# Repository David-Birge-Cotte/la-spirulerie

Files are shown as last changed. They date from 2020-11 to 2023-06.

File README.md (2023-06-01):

# la-spirulerie

www.la-spirulerie.com/

------------------------------------------------------------

/MK3_Firmware

Code source du logiciel officiel installé sur la carte Spirulerie. 
Projet Platform.IO écrit en C++ Arduino pour ESP32. 
Il faut installer l'image système pour le rendu correct des polices d'écriture sur l'interface.

/STL

Modèles 3D à imprimer du bioréacteur Spirulerie et du boitier de carte standalone.

/Guide Bioréacteur Spirulerie

Guide PDF rapide de la culture de spiruline et d'utilisation du bioréacteur Spirulerie.

/LibSpirulerie

Bibliothèque Arduino (PlatformIO) pour simplifier la programmation de la carte Spirulerie. Version 0.0.1 Work in progress

------------------------------------------------------------

/MK3_Firmware

Official firmware installed on La Spirulerie's motherboard.
Platform.IO project written in Arduino C++ for ESP32. 
You need to install file systme image to correctly render fonts.

/STL

3D printable files from La Spirulerie's Bioreactor and standalone board in the STL folder.

/Guide Bioréacteur Spirulerie

(FR) Quick guide about spirulina cultivation and the use of La Spirulerie's bioreactor.

/LibSpirulerie

Arduino (PlatformIO) library to make programming the board easier. Version 0.0.1 Work in progress

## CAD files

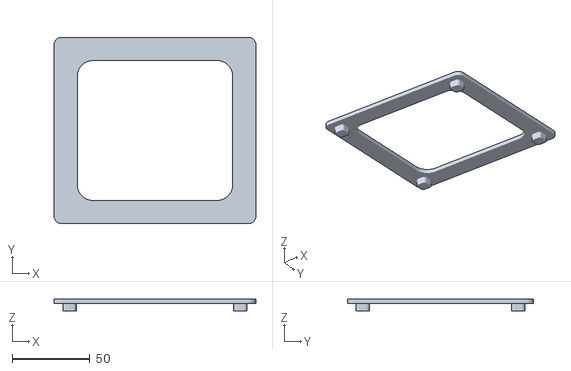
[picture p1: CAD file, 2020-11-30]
STL/boitier/Porte_Boitier.stl
130.0 x 120.0 x 8.00

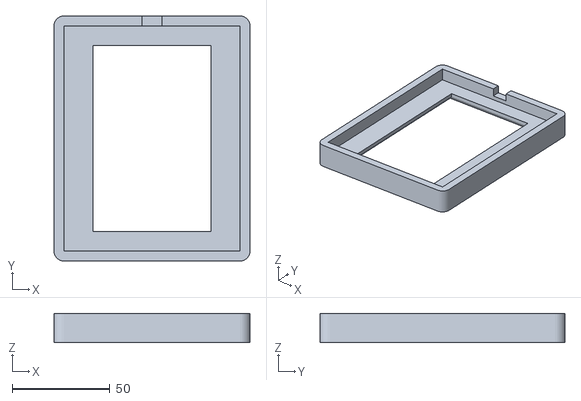
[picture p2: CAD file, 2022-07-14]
STL/chauffage/Protection_chauffage.stl
100.0 x 125.0 x 15.0

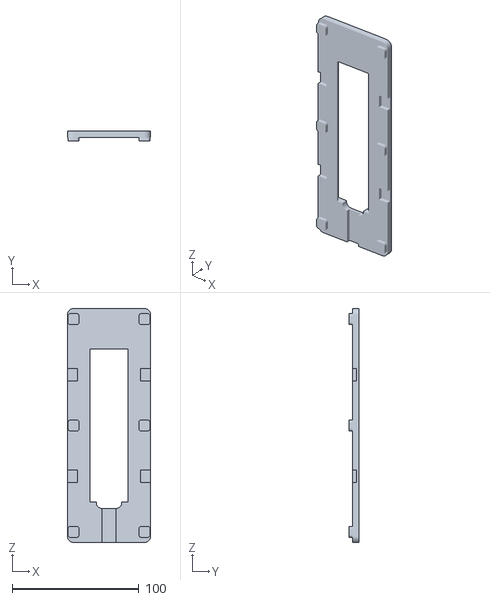
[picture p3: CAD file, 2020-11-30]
STL/couvercle/Côté/Couvercle_COB.stl
65.8 x 7.80 x 184.8

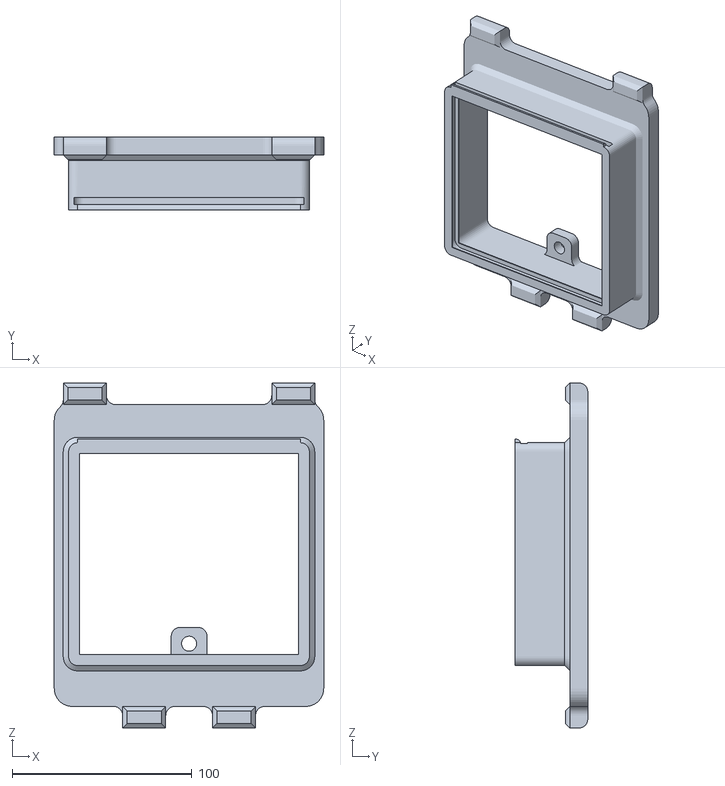
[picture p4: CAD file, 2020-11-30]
STL/couvercle/Recolte/Bac_récolte.stl
150.0 x 40.5 x 192.0

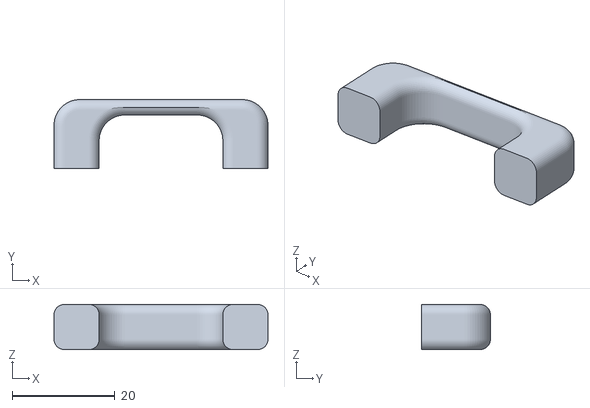
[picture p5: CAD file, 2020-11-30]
STL/interface/passe_cables.stl
41.7 x 13.4 x 8.80

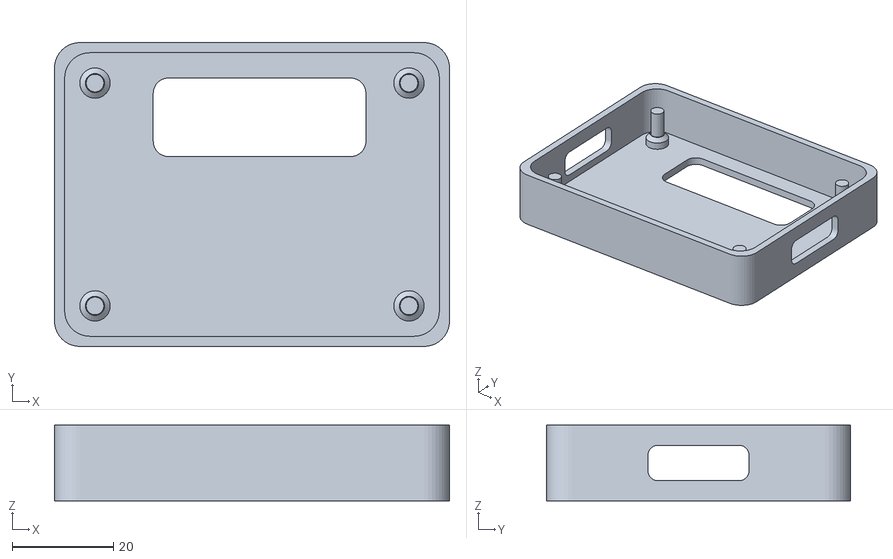
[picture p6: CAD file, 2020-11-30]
STL/interface/standalone/interface_bas_new.stl
78.0 x 60.0 x 15.0

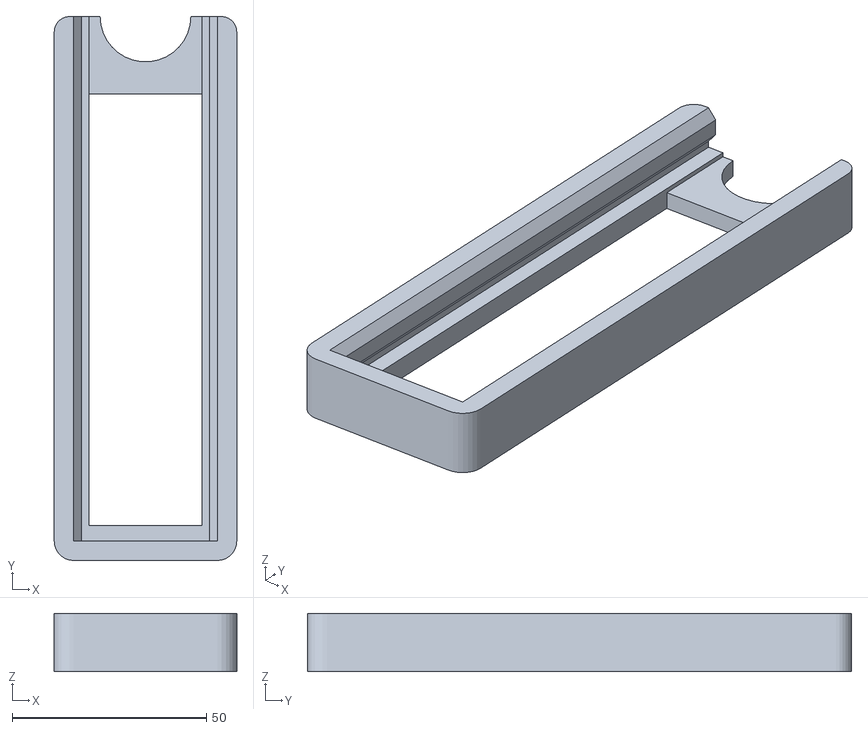
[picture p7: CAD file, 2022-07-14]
STL/porte_LED_collable_120_35.stl
47.0 x 140.0 x 15.0

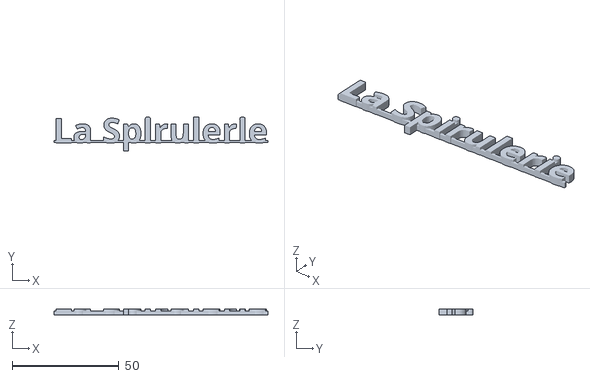
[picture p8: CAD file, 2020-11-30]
STL/white_glued_prints/Spirulerie_Text.stl
100.0 x 16.0 x 3.00

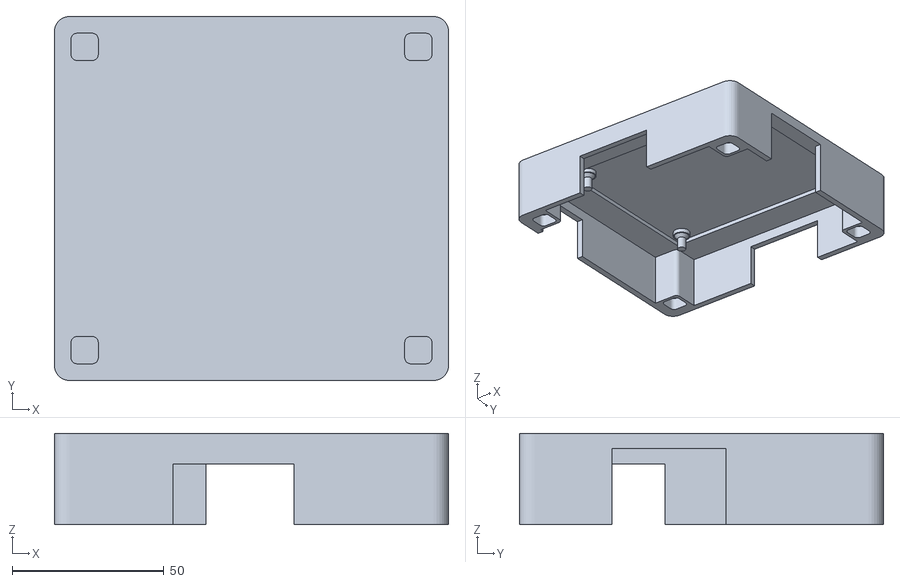
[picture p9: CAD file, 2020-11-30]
STL/boitier/Boitier_PCB.stl
130.0 x 120.0 x 30.0

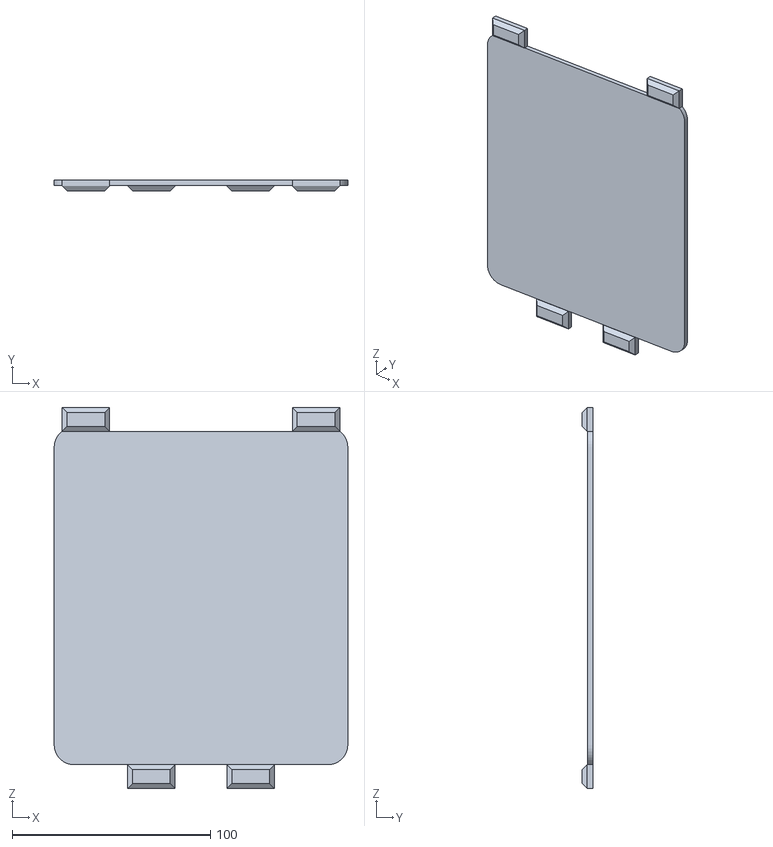
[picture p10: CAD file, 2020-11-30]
STL/couvercle/Centre/Couvercle_fermé _2mm.stl
148.0 x 5.50 x 192.0

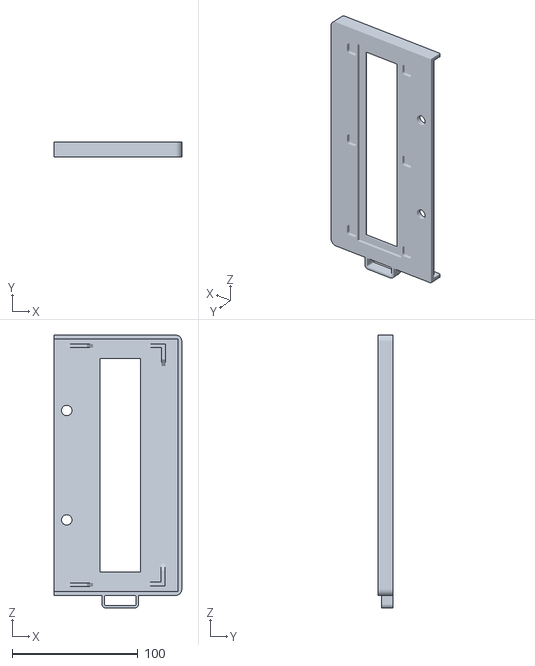
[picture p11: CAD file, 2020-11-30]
STL/couvercle/Côté/Couvercle_base.stl
101.5 x 12.0 x 217.0

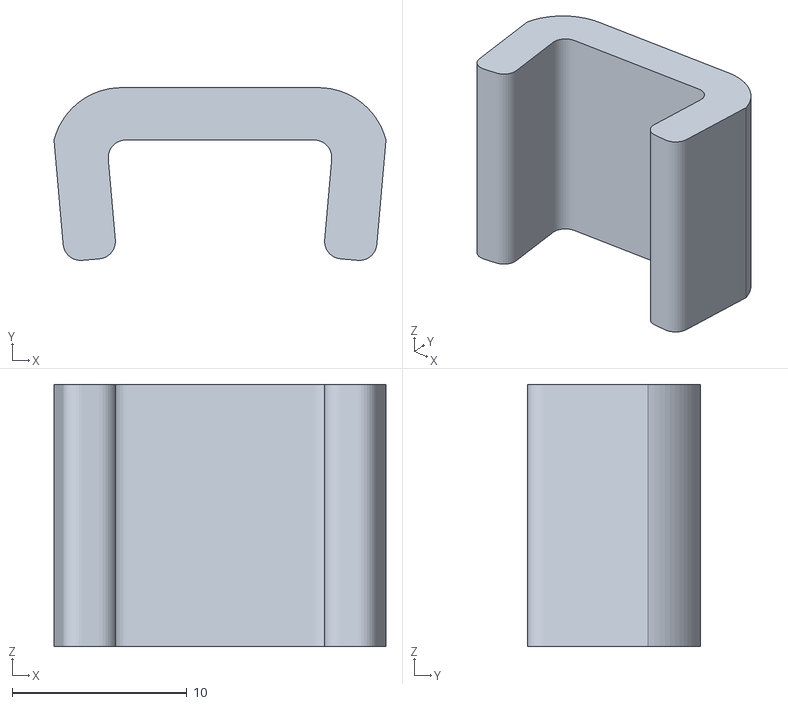
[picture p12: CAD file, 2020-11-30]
STL/couvercle/Recolte/Pince_filtre.stl
19.0 x 9.89 x 15.0

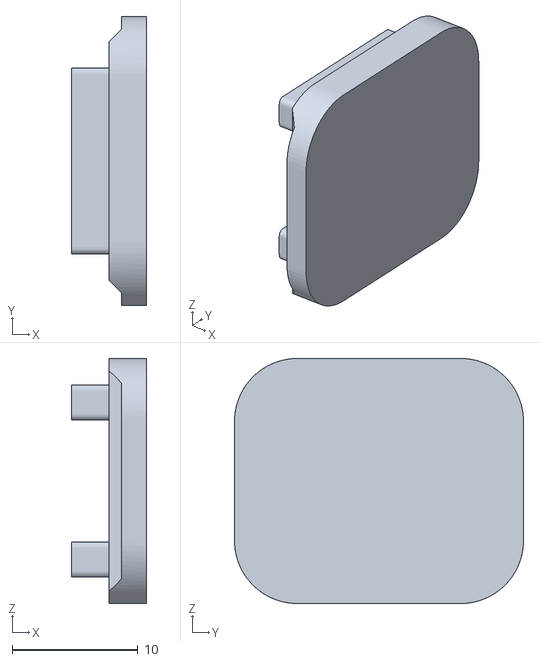
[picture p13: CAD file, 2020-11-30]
STL/interface/attache_interface.stl
6.00 x 23.0 x 19.5

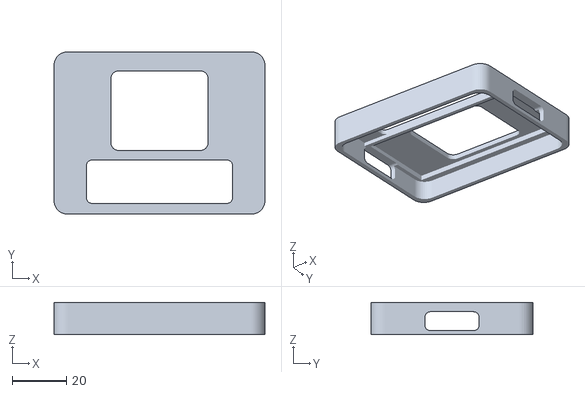
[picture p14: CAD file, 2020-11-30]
STL/interface/standalone/interface_haut_new.stl
78.0 x 60.0 x 12.0

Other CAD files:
STL/couvercle/Centre/Couvercle_centre_fontaine.stl
STL/secchi.stl
STL/white_glued_prints/level_indicator.stl
STL/couvercle/Centre/Couvercle_fermé_4mm.stl
STL/Pied.stl
STL/boitier/Boitier_PCB_screw.stl
STL/boitier/Couvercle_Boitier_PCB.stl
STL/boitier/Porte_Boitier_standalone_8.65.stl
STL/couvercle/Centre/Couvercle_centre_sans_fontaine.stl
STL/couvercle/Côté/Couvercle_protection.stl
STL/couvercle/Côté/Couvercle_protection_radiators.stl
STL/couvercle/Recolte/Passoire_récolte.stl
STL/interface/interface_bas.stl
STL/interface/interface_haut.stl
STL/interface/standalone/interface_attache_new.stl
STL/interface/support_ecran.stl

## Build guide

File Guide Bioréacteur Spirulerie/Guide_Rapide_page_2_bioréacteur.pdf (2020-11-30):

# La Spirulerie

# Guide rapide du kit de culture de spiruline

# 1 - utilisation du Bioréacteur Spirulerie

## Allumage

Verser la spiruline dans le bioréacteur avant puis brancher le bioréacteur via à l'adaptateur founi. Le bioréacteur s'allume (écran, lumières etc). Vérifier que la temperature s'affiche à l'écran (au bout des quelques dizaines de secondes maximum). Si ce n'est pas le cas, débrancher-rebrancher d'abord le bioréacteur puis le thermomètre le cas échéant.

## Croissance

L'objectif des prochains jours est de passer de 1 Litre de spiruline à un bioréacteur rempli. Procédér à des dilutions progressives (cf Secchi / concentration) chaque jour ou deux. Pour le premier jour ajoutez suffisament de milieu de vie (+ nourriture) pour que la pompe placée au plus bas puisse aspirer correctement. Cela correspond à une grande dilution
par rapport à la quantité de spiruline de départ. Attention, toujours rester < 4cm de secchi.

## Récolte

Une fois le bioréacteur rempli jusqu'au marqueur et le secchi vers 2cm la récolte est possible. Activer le menu de pompe manuelle depuis l'interface, placer le bac de récolte,
sécuriser le filtre grâce au clips et placer le tube dans le système du bac de récolte.
Activez la pompe pour laisser passer le milieu de spiruline et le filtrer. Laissez faire pendant quelques minutes en faisant attention à ne pas déborder et ne pas dépasser < 4cm
de secchi. Ne pas oublier de nourrir la spiruline selon la quantité récoltée (une base est 10ml pour une récolte standard de 5 grammes plusieurs fois par semaine).

## Modes de production

Le menu du bioréacteur permet de changer le mode de production.
-> En mode hibernation, la spiruline est conservée à basse temperature, ce qui permet ni croissance ni évaporation.
-> En mode normal, la spiruline se développe de manière optimale avec une temperature de plus de 30°C.
-> En mode customisé, c'est l'utilisateur qui défini les paramètres de culture.

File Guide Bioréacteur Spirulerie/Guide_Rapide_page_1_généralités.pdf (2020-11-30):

# La Spirulerie

# Guide rapide du kit de culture de spiruline

# 0 - principes de base

## Mesure de la concentration

La concentration en spiruline se mesure en centimètres grâce au disque de secchi.
Il se plonge progressivement dans une culture homogène à la verticale depuis la surface. La concentration actuelle est donné par la graduation lorsque le disque devient invisible.

## Concentrations vitales

La concentration en spiruline doit rester entre 2 et 4 cm de secchi pour garder une culture en bonne santé. Il faut donc augmenter les volumes progressivement pour laisser le temps à la spiruline de se redensifier avant une nouvelle ditution de milieu ou de récolte.

## Milieu de vie et nourriture

La spiruline vie dans une eau saumatre, salée et alcaline (PH 8-11.5). C'est cet environnement qui est recréé artificiellement avec de l'eau et les sels de milieu de vie (sel brut, bicarbonate de sodium). Il faut 15g de sels de milieu de vie par litre d'eau.
Ce milieu de vie est utile pour augmenter le volume total de culture

La nourriture de spiruline (azote, phosphore, potassium, magnésium etc..) est livrée dans une bouteille à remplir d'un litre d'eau. Bien agiter avant chaque utilisation et conserver dans un endroit protégé. Utiliser une seringue dédiée pour doser.
Donner 20ml pour 1 litre d'augmentation de milieu de vie ou 20 ml après une récolte de 10g.

## Récolte et conservation

La spiruline se récolte par filtration du milieu de vie. Le filtre lavable de 50 micron (0,05mm) permet de séparer la spiruline de son milieu. Après récolte il faut presser un maximum
la spiruline dans son filtre pour une texture de pate à modeler ou tartinable. Il faut ensuite rapidement placer la spiruline fraîche au réfrigérateur (~1-5°C) dans un récipient fermé
ou elle se conservera pour quelques jours au maximum. Cette spiruline fraîche est la forme la plus nutritive et ne possède pas de gout ni d'odeur. Il est aussi possible de déshydrater la spiruline à moins de 40°C pour une conservation de plusieurs mois en contrepartie d'une perte de certaines qualités nutritionnelles et l'apparition d'odeur et de gout.

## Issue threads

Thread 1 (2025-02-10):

push button must be debouced

Fullmono, 2025-02-10:
Just to mention,
The push buttons are totally unusable, because when I press them, the software registers several presses. The buttons need to be debouced, as is done everywhere with this kind of hardware.
It's an ordeal to adjust even the smallest parameter.

David-Birge-Cotte, 2025-02-10:
Debouncing is already implemented in App.cpp

- line 303: bool Application::IsDebouncedInput(BTN btn) is used for deboucing with hardcoded 100ms between any press of the same button
- line 99: in Application::Update(), button press logic with call to IsDebounced

Never had issues with it. Maybe it's an hardware issue on your end ? buttons lines (io39, 36, 35) should be pulled-down to ground, not left floating. What hardware are you using ?

Fullmono, 2025-02-11:
I use your board, bought in your store

David-Birge-Cotte, 2025-02-11:
Then it's not a software issue as many boards were shipped without any button boucing issue. Please contact me by email if you have an issue with the hardware

Closed 2025-02-11.

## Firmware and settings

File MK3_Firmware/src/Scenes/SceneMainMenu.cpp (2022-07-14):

#include "Scenes/SceneMainMenu.h"
#include "App.h"

// *** PUBLIC INHERITED METHODS ***

void SceneMainMenu::Initialize()
{
	Serial.printf("<== scene Main Menu ==>\n");
	Scene::Initialize();

	app->isOnMainMenu = true;
	app->Graphics.LoadFont("Comfortaa_26", SPIRULERIE_LIGHT, SPIRULERIE_GREEN/*SPIRULERIE_GREY*/);
	app->PlayMelody(Melodies::VALID);
}

void SceneMainMenu::Update()
{

	Scene::Update();
}

void SceneMainMenu::Draw(GraphicsEngine *graphics)
{
	// clear screen
	graphics->DrawScreen(SPIRULERIE_GREY);

	// draw sky and sun / stars
	DrawDayNightCycle(hour(), app->parameters.hour_dawn, app->parameters.hour_dusk);
	// draw green bottom half
	graphics->Screen.fillRect(0, 64, 160, 64, SPIRULERIE_GREEN);
	// show the current temperature
	DrawTemperature(24, 80, app->GetCurrentTemperature());

	//if (app->heatNominal)
	//	graphics->DrawImage(Sprites::chauffage_32_32, 18, 80, 32, 32); // trop moche

	// draw possible moves out of the screen
	graphics->DrawRightArrow();

	Scene::Draw(graphics);
}

void SceneMainMenu::OnButtonClic(BTN btn)
{
	switch (btn)
	{
	case BTN::LEFT:
		//app->LoadScene(new TestScene());
		break;
	case BTN::MIDDLE:
		break;
	case BTN::RIGHT:
		app->isOnMainMenu = false;
		app->LoadScene(new SceneTopMenu());
		break;
	default:
		break;
	}

	Scene::OnButtonClic(btn);
}

void SceneMainMenu::Destroy()
{
	Scene::Destroy();
}

void	SceneMainMenu::DrawDayNightCycle(uint8_t hour, uint8_t dawn, uint8_t dusk)
{
	// check if night
	if (hour < dawn || hour >= dusk)
	{
		// draw the night sky
		app->Graphics.Screen.fillRect(0, 0, 160, 64, SPIRULERIE_GREY);
		for (int i = 0; i < 32; i++)
		{
			float x = SimplexNoise::noise((float)i / 0.37f);
			float y = SimplexNoise::noise((float)i / 0.83f);

			// remap noise from [-1;1] to [0;screen_size]
			x = (x + 1) / 2.0f * 160.0f;
			y = (y + 1) / 2.0f * 64.0f;

			// draw a star
			app->Graphics.Screen.drawPixel(x, y, SPIRULERIE_LIGHT);
		}
		return;
	}

	// draw blue sky
	app->Graphics.Screen.fillRect(0, 0, 160, 64, SPIRULERIE_BLUE);

	uint8_t	num_day_hours = dusk - dawn;
	uint8_t	current_day_hour = hour - dawn;
	uint8_t	percentage_of_day = (uint8_t)((float)current_day_hour / (float)num_day_hours * 100.0f);

	uint8_t	r = 48;
	float	t = (float)map(percentage_of_day, 0, 100, 180, 360) * DEG_TO_RAD;

	uint8_t	sun_x = r*cos(t) + 80;
	uint8_t	sun_y = r*sin(t) + 64 + 16;

	app->Graphics.DrawImage(Sprites::sun_40x40, sun_x - 20, sun_y - 20, 40, 40);
}

void	SceneMainMenu::DrawTemperature(uint16_t x, uint16_t y, float temperature)
{
	app->Graphics.DrawImage(Sprites::thermometer_32x32, x, y, 32, 32);

	app->Graphics.Screen.setCursor(x + 26, y + 6);
	if (temperature != -1)
		app->Graphics.Screen.printf("%.1f°C", temperature);
	else
		app->Graphics.Screen.printf(". . . . °C");
}

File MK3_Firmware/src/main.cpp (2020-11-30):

#include <Arduino.h>
#include "App.h"

Application App; // Global Application class with singleton reference

void setup()
{
	#ifdef SERIAL_DEBUG
		// Start serial connexion
		Serial.begin(112500);
		delay(1000); // wait for serial to connect
	#endif

	InitApplication(); // Starts the program
}

void loop()
{
	// program is done in tasks
}

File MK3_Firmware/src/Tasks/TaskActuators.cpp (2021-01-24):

#include "Tasks/TaskActuators.h"

TaskHandle_t InitActuators()
{
	TaskHandle_t	handle;

	#ifdef SERIAL_DEBUG
		Serial.println("- Actuators init ..");
	#endif

	xTaskCreate(
		ActuatorTask, "Actuators", 4096, NULL, 1, &handle);

	return (handle);
}

void ActuatorTask(void *parameter)
{
	// Queue of actions coming from Application
	QueueHandle_t	actionQueue = Application::singleton->PWMActionsQueue;

	// Queues to use with PWM tasks
	QueueHandle_t	IOAQueue = xQueueCreate(5, sizeof(ActuatorPWMAction));
	QueueHandle_t	IOBQueue = xQueueCreate(5, sizeof(ActuatorPWMAction));
	QueueHandle_t	IOCQueue = xQueueCreate(5, sizeof(ActuatorPWMAction));
	QueueHandle_t	IODQueue = xQueueCreate(5, sizeof(ActuatorPWMAction));
	//QueueHandle_t	BrightnessQueue = xQueueCreate(5, sizeof(ActuatorPWMAction));

	// Create different tasks for non blocking independant PWM channel control
	xTaskCreate(Task_IO_A, "IO_A", 2048, IOAQueue, 2, NULL);
	xTaskCreate(Task_IO_B, "IO_B", 2048, IOBQueue, 2, NULL);
	xTaskCreate(Task_IO_C, "IO_C", 2048, IOCQueue, 2, NULL);
	xTaskCreate(Task_IO_D, "IO_D", 2048, IODQueue, 2, NULL);
	//xTaskCreate(Task_Brightness, "BRIGHTNESS", 2048, BrightnessQueue, 2, NULL);

	Serial.printf("--> all actuator task started\n");

	for (;;)
	{
		ActuatorPWMAction action;

		// Wait indefinitely to receive an action
		xQueueReceive(actionQueue, &action, portMAX_DELAY);

		// direct actions to specific tasks driving PWM channels
		if (action.channel == PWMC_A)
			xQueueSend(IOAQueue, &action, portMAX_DELAY);
		if (action.channel == PWMC_B)
			xQueueSend(IOBQueue, &action, portMAX_DELAY);
		if (action.channel == PWMC_C)
			xQueueSend(IOCQueue, &action, portMAX_DELAY);
		if (action.channel == PWMC_D)
			xQueueSend(IODQueue, &action, portMAX_DELAY);
		//if (action.channel == PWMC_BRIGHTNESS)
		//	xQueueSend(BrightnessQueue, &action, portMAX_DELAY);
	}
}

void	Task_IO_A(void *parameter)
{
	InitPWM(PWMC_A, PWM_FREQ_IO, PORT_A);
	ChannelTaskFunc(PWMC_A, (QueueHandle_t)parameter);
}

void	Task_IO_B(void *parameter)
{
	InitPWM(PWMC_B, PWM_FREQ_IO, PORT_B);
	ChannelTaskFunc(PWMC_B, (QueueHandle_t)parameter);
}

void	Task_IO_C(void *parameter)
{
	InitPWM(PWMC_C, PWM_FREQ_IO, PORT_C);
	ChannelTaskFunc(PWMC_C, (QueueHandle_t)parameter);
}

void	Task_IO_D(void *parameter)
{
	InitPWM(PWMC_D, PWM_FREQ_IO, PORT_D);
	ChannelTaskFunc(PWMC_D, (QueueHandle_t)parameter);
}

/*void	Task_Brightness(void *parameter)
{
	InitPWM(PWMC_BRIGHTNESS, PWM_FREQ_LCD, PIN_LCDLIGHT);
	ChannelTaskFunc(PWMC_BRIGHTNESS, (QueueHandle_t)parameter);
}*/

// This function is the main loop of the RTOS task for the PWM channel
void	ChannelTaskFunc(uint8_t channel, QueueHandle_t queue)
{
	uint16_t		current_duty = 0;
	uint16_t 		target_duty = 0;

	for (;;)
	{
		ActuatorPWMAction action;
		xQueueReceive(queue, &action, portMAX_DELAY);

		target_duty = action.percentage * (float)PWM_MAX_RESOLUTION / 100.0f;
		PWM_Fade(channel, current_duty, target_duty, action.speed);
		current_duty = target_duty;
	}
}

// Initialize the pin and pwm channel
void	InitPWM(uint8_t channel, double frequency, uint8_t pin)
{
	pinMode(pin, OUTPUT);
	ledcSetup(channel, frequency, PWM_RESOLUTION_BITS);
	ledcAttachPin(pin, channel);
}

// Outputs PWM on selected channel
void	PWM_Write(uint8_t channel, uint16_t duty)
{
	ledcWrite(channel, duty);
}

// Fades the PWM channel to a new value in a specific timing
void	PWM_Fade(uint8_t channel, uint16_t from_duty, uint16_t to_duty, uint32_t ms)
{
	int8_t		sign;
	int16_t		diff;

	if (from_duty == to_duty)
		return;

	sign = (to_duty > from_duty ? 1 : -1);
	diff = (to_duty - from_duty) * sign;

	while (from_duty != to_duty)
	{
		PWM_Write(channel, from_duty);
		from_duty += sign;
		delay(ms / diff);
	}
	PWM_Write(channel, to_duty);
}

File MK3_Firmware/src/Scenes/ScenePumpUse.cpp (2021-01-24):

#include "Scenes/ScenePumpUse.h"
#include "App.h"

// *** SOME C ENUMS (to cast as uint8_t) ***
enum	PUMP_SCENE_STATE { PREPARATION, PUMP_USE, STOP, EXIT };
enum	PUMP_MODE { HARVEST_SLOW, HARVEST_MEDIUM, HARVEST_FAST, PURGE };

// *** Update Functions ***

static void	PumpHarvestSlow(tmElements_t *time)
{
	if (time->Second % 6 < 3)
		Application::singleton->ChangePump(100, 500);
	else
		Application::singleton->ChangePump(0, 500);
}

static void	PumpHarvestMedium(tmElements_t *time)
{
	if (time->Second % 6 < 4)
		Application::singleton->ChangePump(100, 500);
	else
		Application::singleton->ChangePump(0, 500);
}

static void	PumpHarvestFast(tmElements_t *time)
{
	if (time->Second % 6 < 5)
		Application::singleton->ChangePump(100, 500);
	else
		Application::singleton->ChangePump(0, 500);
}

static void	PumpPurge()
{
	Application::singleton->ChangePump(100, 500);
}

static void PumpUsageUpdate(uint8_t pump_mode)
{
	tmElements_t	time = TimeSystem::GetTime();

	switch (pump_mode)
	{
	case HARVEST_SLOW:
		PumpHarvestSlow(&time);
		break;
	case HARVEST_MEDIUM:
		PumpHarvestMedium(&time);
		break;
	case HARVEST_FAST:
		PumpHarvestFast(&time);
		break;
	case PURGE:
		PumpPurge();
		break;
	default:
		break;
	}
}

// *** Draw Functions ***

static void	PumpPreparationDraw(GraphicsEngine *graphics)
{
	graphics->Screen.textcolor = SPIRULERIE_GREY;
	graphics->Screen.drawString(TextContent::text_pump_preparation_01_FR, 80, 54);
	graphics->Screen.drawString(TextContent::text_pump_preparation_02_FR, 80, 74);

	graphics->Screen.textcolor = SPIRULERIE_RED;
	graphics->Screen.drawString(TextContent::text_start_FR, 80, 100);
}

static void	PumpUsageDraw(GraphicsEngine *graphics, uint8_t pump_mode)
{
	switch (pump_mode)
	{
	case HARVEST_SLOW:
		graphics->Screen.fillRoundRect(12, 56, 32, 32, 4, SPIRULERIE_RED);
		break;
	case HARVEST_MEDIUM:
		graphics->Screen.fillRoundRect(46, 56, 32, 32, 4, SPIRULERIE_RED);
		break;
	case HARVEST_FAST:
		graphics->Screen.fillRoundRect(82, 56, 32, 32, 4, SPIRULERIE_RED);
		break;
	case PURGE:
		graphics->Screen.fillRoundRect(116, 56, 32, 32, 4, SPIRULERIE_RED);
		break;
	default:
		break;
	}

	graphics->Screen.drawRoundRect(12, 56, 32, 32, 4, SPIRULERIE_GREEN);
	graphics->Screen.drawRoundRect(46, 56, 32, 32, 4, SPIRULERIE_GREEN);
	graphics->Screen.drawRoundRect(82, 56, 32, 32, 4, SPIRULERIE_GREEN);
	graphics->Screen.drawRoundRect(116, 56, 32, 32, 4, SPIRULERIE_GREEN);

	graphics->DrawImage(Sprites::I_32_32, 12, 56, 32, 32);
	graphics->DrawImage(Sprites::II_32_32, 46, 56, 32, 32);
	graphics->DrawImage(Sprites::III_32_32, 82, 56, 32, 32);
	graphics->DrawImage(Sprites::IV_32_32, 116, 56, 32, 32);

	graphics->Screen.textcolor = SPIRULERIE_RED;
	graphics->Screen.drawString(TextContent::text_stop_FR, 80, 100);
}

static void	PumpStopDraw(GraphicsEngine *graphics)
{
	graphics->Screen.textcolor = SPIRULERIE_GREY;
	graphics->Screen.drawString(TextContent::text_pump_stop_01_FR, 80, 64);

	graphics->Screen.textcolor = SPIRULERIE_RED;
	graphics->Screen.drawString(TextContent::text_validate_FR, 80, 100);
}

// *** Public Methods Overriding ***

void	ScenePumpUse::Initialize()
{
	Serial.printf("<== scene ScenePumpUse ==>\n");
	Scene::Initialize();

	app->pumpNominal = false; // Tell the app NOT to update the pump anymore
	app->SendAction(PWMC_D, 0, 500); // Tell the pump to stop

	// clear screen
	app->Graphics.Screen.fillSprite(SPIRULERIE_LIGHT);

	// draw title
	app->Graphics.LoadFont("Comfortaa_26", SPIRULERIE_BLUE, SPIRULERIE_LIGHT);
	app->Graphics.Screen.setTextDatum(TC_DATUM);
	app->Graphics.Screen.drawString(TextContent::text_menu_pump_FR, 80, 16);

	// Load font to use all other functions / in Draw()
	app->Graphics.LoadFont("Comfortaa_16", SPIRULERIE_GREY, SPIRULERIE_LIGHT);
}

void	ScenePumpUse::OnButtonClic(BTN btn)
{
	switch (btn)
	{
	case BTN::LEFT:
		if (m_progress == PUMP_USE && m_pump_mode > HARVEST_SLOW)
			m_pump_mode--;
		break;
	case BTN::MIDDLE:
		m_progress++;
		break;
	case BTN::RIGHT:
		if (m_progress == PUMP_USE && m_pump_mode < PURGE)
			m_pump_mode++;
		break;
	default:
		break;
	}

	Scene::OnButtonClic(btn);
}

void	ScenePumpUse::Destroy()
{
	Scene::Destroy();
}

void	ScenePumpUse::Update()
{
	switch (m_progress)
	{
	case PREPARATION:
		break;
	case PUMP_USE:
		PumpUsageUpdate(m_pump_mode);
		break;
	case STOP:
		app->SendAction(PWMC_D, 0, 500);
		break;
	case EXIT:
		app->pumpNominal = true; // Give back control of the pump to the App
		app->LoadScene(new SceneMainMenu());
		break;
	default:
		break;
	}

	Scene::Update();
}

void	ScenePumpUse::Draw(GraphicsEngine *graphics)
{
	// only clean below the title
	graphics->Screen.fillRect(0, 50, 160, 78, SPIRULERIE_LIGHT);

	switch (m_progress)
	{
	case PREPARATION:
		PumpPreparationDraw(graphics);
		break;
	case PUMP_USE:
		PumpUsageDraw(graphics, m_pump_mode);
		break;
	case STOP:
		PumpStopDraw(graphics);
		break;
	case EXIT:
		break;
	default:
		break;
	}

	Scene::Draw(graphics); // push sprite to screen
}

// *** PRIVATE METHODS ***

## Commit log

2020-11-30 release nov 2020
    [Bac_récolte.stl, Boitier_PCB.stl, Boitier_PCB_screw.stl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]
2021-03-05 fixes and small upgrades: -fix critical crash on custom mode with pump cycle of 0. -add customizability of B channel light intensity PWM % independant from channel A -wip begin work on new more gener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
    [App.cpp, App.h, Popup.cpp]
2022-07-14 mise à jour STL
    [Gluable_LED_Hodler.stl, Protection_chauffage.stl, porte_LED_collable_120_35.stl]
